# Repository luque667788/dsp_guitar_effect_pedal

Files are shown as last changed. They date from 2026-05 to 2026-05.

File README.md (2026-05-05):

# Noise Maker V1
### Digital Guitar Effect Pedal Prototype with Audio DSP

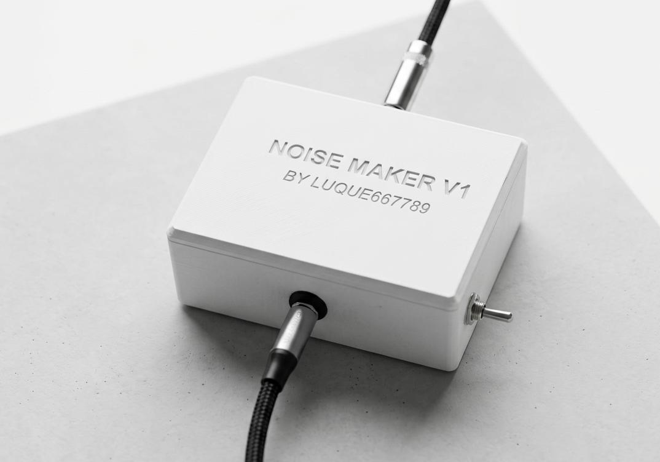
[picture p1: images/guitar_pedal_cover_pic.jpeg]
Noise Maker V1


## Overview

A digital guitar pedal that implements an echo effect on the signal between guitar and amplifier, based on an STM32H7 and custom analog circuits. This is a semester project I built at Hochschule Ravensburg-Weingarten to bring the fundamentals from my theoretical courses (Communication Technology, Computer Technology, Signal Analysis in Time and Frequency Domains, DSP Basics, and Electronic Circuit Design) together into one thing I could plug into and play through (literally :).

Of course this is just a prototype, so there is plenty that can still be improved, especially on the hardware side. More updates will follow as time allows.

The full report and the presentation slides are in [`docs/`](docs/).

## Features

- Real-time audio DSP on a live guitar signal.
- ADC and DAC streaming over DMA, no polling.
- Hardware-timer-driven, interrupt-based sampling pipeline.
- Double-buffering between ADC, memory, and DAC.
- Zero-copy ring buffer for the echo line. Geometric series echo fading.
- Custom analog frontend and backend, designed from scratch around the STM32's built-in converters.
- Filtering before the ADC and after the DAC (sampling-theory-driven, report explains in detail).
- Falstad circuit simulation up front, KiCad schematics for the final design.
- Output noise measured and analyzed in the frequency domain with Audacity (possible sources of noise and future improvements discussed in the report).
- Firmware in C, end-to-end working MVP from analog input to analog output.
- 3D-printed enclosure, 9 V battery powered.

## How it works

The guitar signal is conditioned by an analog frontend, sampled on the STM32H743, processed in real time, and returned through an analog backend to a level the amplifier accepts. A hardware timer drives the sampling, DMA streams the samples in and out with double-buffering, and the delay itself is a ring buffer in memory where only the indexes move. The full design (clock tree, filtering, DSP loop, noise analysis) is explained in detail in the [report](docs/report.pdf). For a high-level overview, see the [presentation slides](docs/presentation.pdf).

## Toolchain

Built with the STM32 toolchain. Peripherals configured in STM32CubeMX, firmware compiled with `arm-none-eabi-gcc` through CMake, flashed over ST-Link.

## What is in this repo

You will find the firmware source code, the KiCad circuit schematics, and the scientific report and presentation slides.

```
.
├── docs/                    slides and scientific report
├── guitar_pedal_software/   STM32H743 firmware
├── kicad/guitarpedalv2/     KiCad schematic and PCB project
└── images/                  schematics, photos, scope captures
```

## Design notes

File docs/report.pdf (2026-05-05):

## Author: Luiz Henrique Mendonça Nr. 17442671

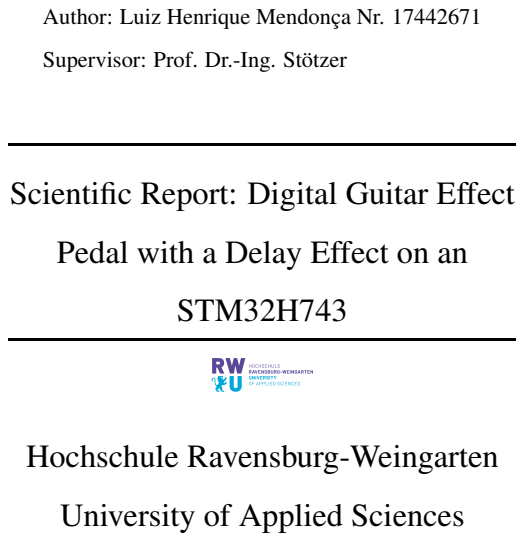
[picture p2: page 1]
STM32H743

Supervisor: Prof. Dr.-Ing. Stötzer

Scientific Report: Digital Guitar Effect

Pedal with a Delay Effect on an

Hochschule Ravensburg-Weingarten

University of Applied Sciences

## Contents

1 Abstract | 2
2 Introduction | 3
3 Materials and Methods | 6
4 Results | 10
5 Discussion | 24
6 Glossary | 27
7 Bibliography | 28

## 1 Abstract

This report describes the design and build of a digital guitar effect pedal that adds

an echo (delay) to the signal of an electric guitar. The pedal sits in the signal

chain between the guitar and the amplifier, and is built around an STM32H743

microcontroller with a minimal analog frontend and backend based on a single

MCP6002 dual op-amp running on a 3.3 V single supply. The frontend conditions

the weak guitar signal so that it can be sampled by the on-chip ADC. The firmware

stores each sample in a circular buffer and plays it back 300 ms later mixed with the

live signal. The backend brings the processed output back to a level and impedance

that a guitar amplifier accepts. The full chain was designed, simulated, prototyped

on a breadboard, soldered onto a protoboard, and finally mounted in a 3D-printed

enclosure. The prototype produced a clearly audible echo on real guitar input,

fulfilling the proposed goals.

2

## 2 Introduction

A delay pedal stores what the guitar plays and repeats it a short time later. The

listener hears the original note and then a quieter copy of it; if part of the copy is

fed back into the delay line, the echoes repeat and gradually fade. The effect has

been used in guitar music since the tape-echo devices of the 1950s, and today it

can be reproduced with a microcontroller and a handful of passive components. It

is a good showcase for a digital effect pedal precisely because long, clean delays

are difficult to achieve in purely analog hardware.

Compared to dedicated audio codecs or application-specific DSP chips, this

minimal-BOM approach leverages the high clock speed and built-in converters

of the STM32H7, alongside a standard single-supply op-amp. This design trades

audio fidelity for hardware simplicity, providing a practical context to explore

mixed-signal embedded engineering constraints.

The central technical problem is moving the analog signal in and out of the

digital domain without introducing noise. A guitar pickup produces a continuous

voltage that swings symmetrically around ground, while a microcontroller works

with discrete numbers sampled at a fixed rate. On top of that, the Nyquist theorem

requires that no frequency component above half the sampling rate reaches the

converter; otherwise that energy folds back into the audible band as aliasing and

produces tones that were never in the original signal. To prevent this, a low-pass

filter is placed before the ADC to remove out-of-band content before sampling,

and an identical filter is placed after the DAC to smooth the stepped output back

into a continuous signal. At a sampling rate of 48 kHz the Nyquist limit limit is

24 kHz, which covers the full audible range. In practice the energy of music sits

well below this limit. Figure 1 shows the frequency distribution of a typical music

signal: most of the energy is below 5 kHz and the audible range tapers off well

before 20 kHz. The anti-alias and reconstruction filters in this project were sized

3

with this in mind.

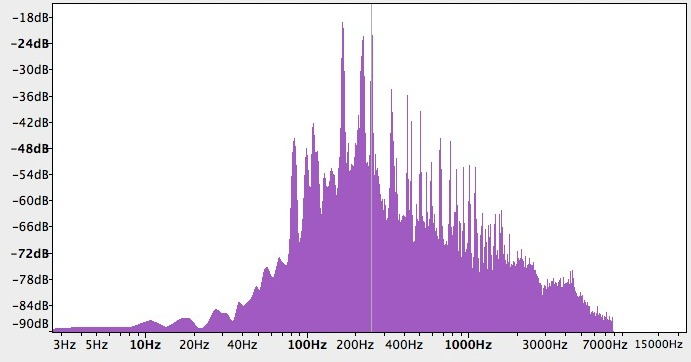
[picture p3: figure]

Figure 1: Frequency distribution of a typical music signal. Most energy is below

5 kHz and the audible range tapers off well before 20 kHz.

The analog signal path uses an op-amp as a unity-gain buffer at the input and

at the output, to give the filter stages a high input impedance toward the guitar

pickup and a low output impedance toward the next stage, so the cutoff of each RC

filter is not pulled by the connected load. A high-pass filter at the output removes

the DC bias that the single-supply circuit adds to the signal, before it reaches

the downstream amplifier. At the ADC input, a pair of BAT54S Schottky diodes

clamps the pin to the supply rails to protect the converter from over-voltage.

On the digital side, a hardware timer drives the sample rate by firing an update

event at 48 kHz, which starts an ADC conversion and latches a DAC output in

hardware without involving the processor. DMA moves data between the converter

peripherals and memory buffers, so the CPU is free to run the delay algorithm

while transfers proceed in the background. Double buffering divides the DMA

buffer into two halves: the hardware fills one half while the processor works on the

other, keeping the audio stream continuous with no gap between conversions.

The goal of this project was to build a working delay pedal at 48 kHz with up to

300 ms of delay, using a single MCP6002 [2] dual op-amp for both analog stages

4

on a 3.3 V supply, and an STM32H743 microcontroller [1] for the digital signal

processing. The project question follows from the goal: Can a working digital

delay effect for an electric guitar be built around an STM32H743 and a single

MCP6002 dual op-amp on a 3.3 V single supply, producing an audible echo on

real guitar input?

5

## 3 Materials and Methods

### 3.1 Materials Used

The microcontroller used was an STM32H743VIT6 [1] on a WeAct Mini devel-

opment board (Figure 2). It is an ARM Cortex-M7 running at up to 480 MHz,

with a 16-bit ADC, a 12-bit DAC, and a DMA controller that moves data between

peripherals and memory without CPU involvement. The analog stages were built

around one MCP6002 dual op-amp and a small set of resistors and capacitors. Two

6.35 mm TS jack jacks carry the input and output signals. All the components and

their values are documented in the circuit diagrams. A Bill of Material (BoM) can

also be provided as an attachment.

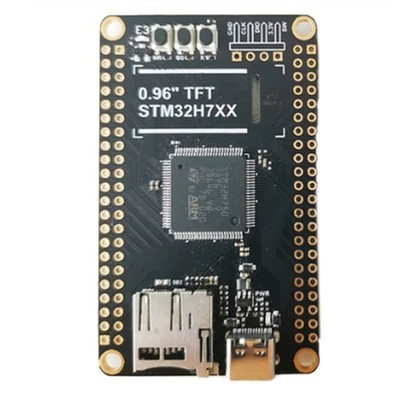
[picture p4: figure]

Figure 2: WeAct Mini STM32H743 development board.

The following tools were used during the project:

- STM32CubeMX, to generate the peripheral initialization code.
- arm-none-eabi-gcc version 12 as cross-compiler, called from CMake.
- KiCad 8, for the schematic capture.

6

- Falstad Circuit Simulator, to check the full analog signal path in the browser

before building it.

- A guitar, a guitar amplifier, and an oscilloscope, for listening tests and

waveform verification.

- Audacity 3, for recording and analysing the pedal output during the verifica-

tion measurements.

### 3.2 Methods

A top-down approach was taken for developing the system architecture. The

sampling rate was fixed first at 48 kHz, which set the Nyquist limit and from there

the cutoff of the anti-alias filter. 48 kHz was chosen over the 44.1 kHz CD rate

because it is the standard rate of professional digital audio equipment and divides

evenly into the 240 MHz timer clock, which avoids drift between the timer period

and the actual sample rate. The component values were then calculated based on

that and the input range the ADC needs based on the STM32 datasheet (so we

know which input and output are expected from the ADC and DAC). Each analog

stage was built on a breadboard and tested on its own with a signal generator before

being connected to the microcontroller, so that problems could be isolated to one

part of the chain at a time.

The firmware was developed in parallel with the hardware. STM32CubeMX

was used to generate the initialization code for the ADC, DAC, timer, and DMA

peripherals; the DSP loop was then developed in a separate module (dsp.h) and

integrated into the DMA callbacks. The code was compiled with CMake and

flashed over ST-Link. The waveforms were verified on the oscilloscope using a

simulated signal from a frequency generator, which made it possible to test the

firmware on its own without depending on the analog stages. The circuit was then

7

moved from the breadboard to a hand-soldered protoboard and assembled in a

3D-printed enclosure (Figure 3).

The verification measurements (results documented in Section 4.6) used the

setup: A 300 Hz sine wave generated on the laptop was sent from the laptop

headphone output into the pedal input jack J1, processed by the pedal, fed into

the guitar amplifier, and recorded back into Audacity through the amplifier’s

USB output at 48 kHz, 16-bit. A second recording was taken with the laptop

disconnected from J1, capturing the noise alone. Both recordings used identical

amplifier and recorder gain settings, so the gain factor cancels in the ratio of the

two and the system SNR can be derived directly from the dBFS difference between

them.

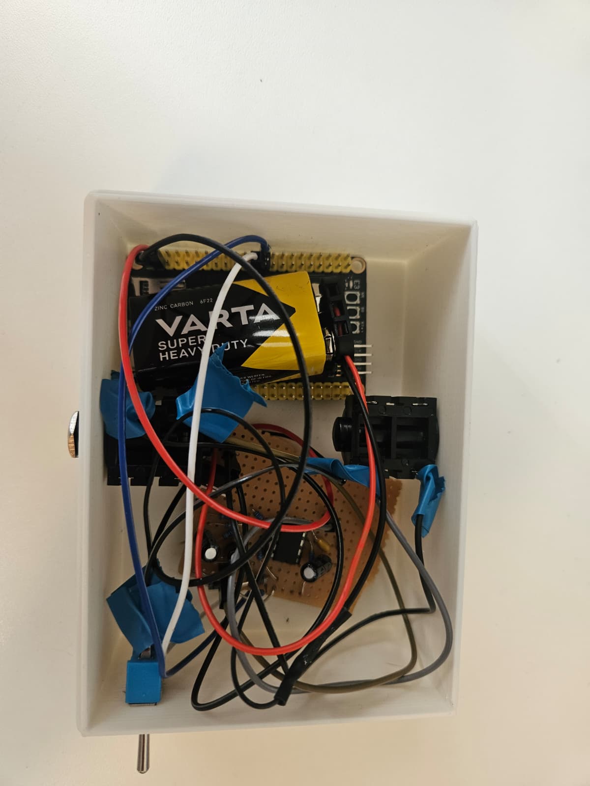
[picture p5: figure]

Figure 3: Final prototype in its 3D-printed enclosure, powered by a 9 V battery.

8

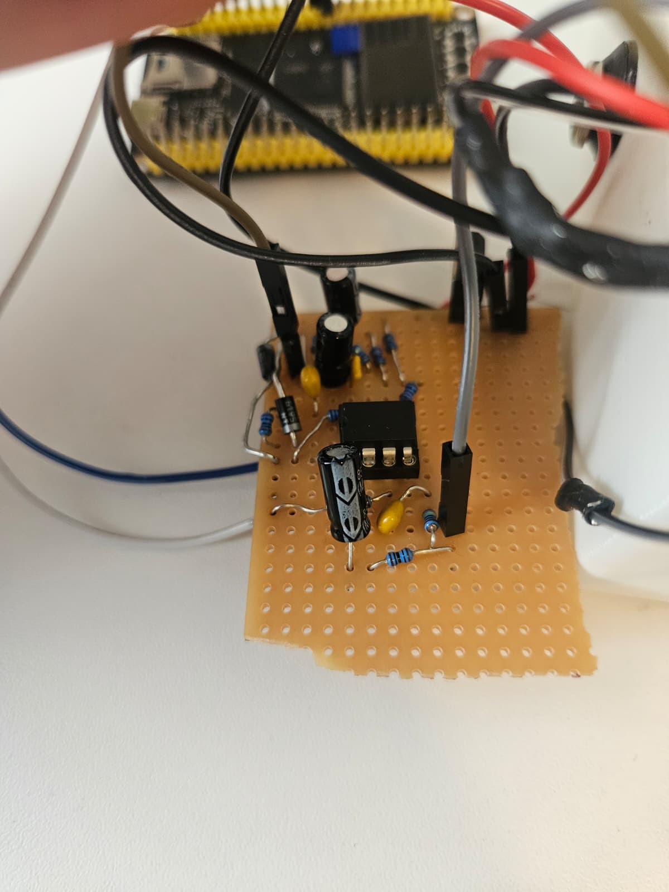
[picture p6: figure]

Figure 4: Hand-soldered protoboard with the analog frontend, backend, and

STM32H743 development board.

9

## 4 Results

The results is the design of a system that was divided in two main parts: the analog

frontend/backend, and the software architecture of the firmware. In the sections

below both designs are described and explained:

### 4.1 Analog Frontend

The frontend conditions the guitar signal before it reaches the ADC. Figure 5 shows

the schematic. Signal flow is left to right; each component is described below.

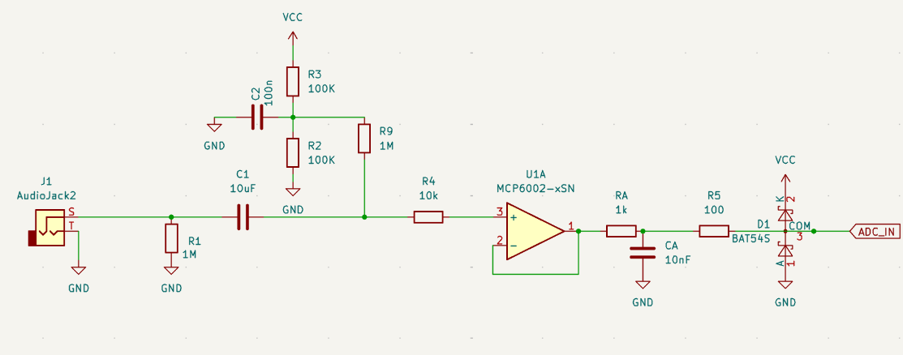
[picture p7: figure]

Figure 5: Analog frontend: guitar input to ADC pin.

J1 — 6.35 mm TS jack. Guitar input.

R1 — 1 MΩ to GND. Sets input impedance to 1 MΩ, which is what a guitar

pickup expects. Also bleeds charge off C1 when the cable is unplugged, preventing

a pop on reconnection.

C1 — 10 µF. AC-coupling capacitor. Blocks any DC from the source; passes

audio. The high-pass corner with R1 is

fc =

1
2π · 1 MΩ · 10 µF
≈ 0.016 Hz, | (4.1)

well below the lowest guitar note, so no signal is lost.

10

R2, R3 — 100 kΩ each (bias divider). Divide the 3.3 V supply to produce a

DC midpoint:

Vbias =

3.3
2
= 1.65 V. | (4.2)

The guitar signal swings around 0 V; the ADC input range is 0 V to 3.3 V. Lifting

the signal onto the 1.65 V midpoint centers its swing inside the full ADC range.

C2 — 100 nF. Decouples the bias node to GND. Keeps the 1.65 V reference

stable against VCC variations.

R9 — 1 MΩ. Connects the bias node to the signal path. The Thévenin

impedance of R2/R3 is 50 kΩ. Without R9, that 50 kΩ would load the signal

and interact with the source impedance, attenuating high frequencies (tone suck).

R9 raises the impedance seen by the signal to 50 kΩ + 1 MΩ ≈ 1.05 MΩ, which is

negligible next to R1.

R4 — 10 kΩ. Series resistor at the op-amp non-inverting input. Limits input

current in fault conditions and damps any resonance with op-amp input capacitance.

U1A — MCP6002, unity-gain buffer. Output tied directly to inverting input.

Input impedance ≈ 10¹² Ω; output impedance < 1 Ω. Isolates the high-impedance

bias divider from the low-impedance filter that follows.

RA, CA — 1 kΩ and 10 nF C0G. Anti-aliasing low-pass filter:

fc =

1
2π · 1 kΩ · 10 nF
≈ 15.9 kHz. | (4.3)

The cutoff sits above the band where musical content lives (Figure 1) and below the

24 kHz Nyquist limit, so it removes out-of-band energy before sampling without

cutting useful signal.

R5 — 100 Ω. Protection resistor at the ADC pin. Limits fault current through

the STM32 internal ESD diodes if a transient drives the pin outside the supply

rails.

D1 — BAT54S dual Schottky. Clamp diodes at the ADC pin. One diode from

11 pin to VCC, one from pin to GND. Forward voltage ≈ 0.3 V: the pin is clamped to

the range [−0.3 V, 3.6 V] before any transient reaches the converter input.

### 4.2 Analog Backend

The backend converts the DAC output back to a line-level audio signal. Figure 6

shows the schematic. Signal flow is left to right; each component is described

below.

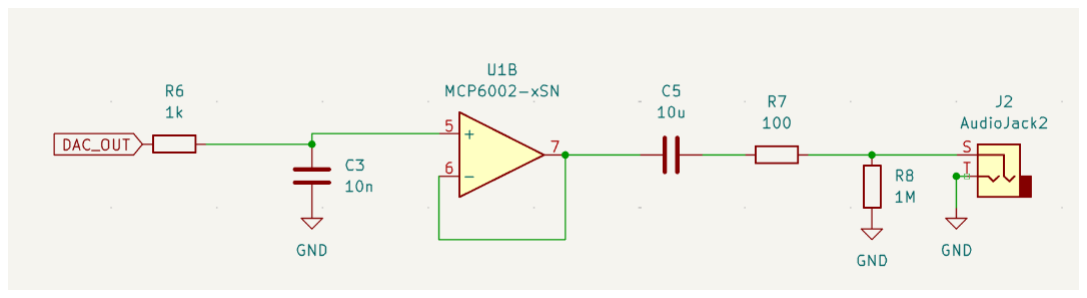
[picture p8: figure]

Figure 6: Analog backend: DAC output to amplifier jack.

R6 — 1 kΩ. Series resistor at the DAC output. Together with C3 it forms the

reconstruction low-pass filter (see C3 below).

C3 — 10 nF C0G. Together with R6, forms the reconstruction low-pass filter:

fc =

1
2π · 1 kΩ · 10 nF
≈ 15.9 kHz. | (4.4)

The DAC holds each sample constant until the next clock tick, producing a staircase

waveform. The filter smooths those steps before the signal reaches the op-amp.

The cutoff matches the anti-aliasing filter on the frontend, so both edges of the

digital window are treated symmetrically.

U1B — MCP6002, unity-gain buffer. Second channel of the same dual

op-amp used in the frontend. Output tied directly to inverting input. Presents a

high-impedance load to C3 so the filter corner stays at 15.9 kHz, and drives the

output network from a low-impedance source.

12

C5 — 10 µF. AC-coupling capacitor at the op-amp output. The DAC runs with

a 1.65 V DC midpoint bias; C5 blocks this offset so the output delivered to the

amplifier is centered on 0 V.

R7 — 100 Ω. Series resistor at the output node. Limits fault current through

the op-amp output stage if the jack is shorted or connected to a low-impedance

load, and damps any cable capacitance resonance.

R8 — 1 MΩ to GND. Bleeder resistor at the output node. Provides a DC return

path so C5 does not float the output when no amplifier is connected. Also forms a

high-pass corner with C5:

fc =

1
2π · 1 MΩ · 10 µF
≈ 0.016 Hz, | (4.5)

negligible relative to the audio band.

J2 — 6.35 mm TS jack. Output to guitar amplifier.

13

The full analog path was also entered into the Falstad simulator to check the

frontend and the backend together before building the circuit. Figure 7 shows the

simulated chain.

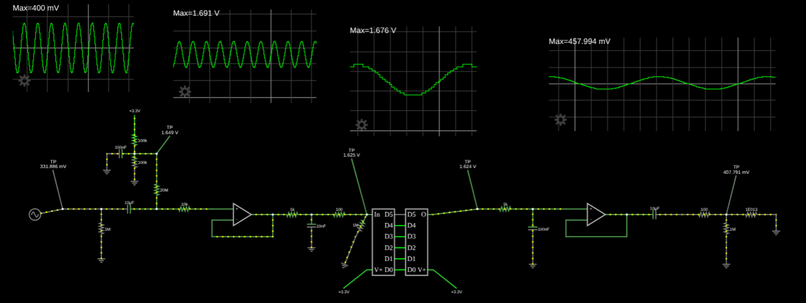
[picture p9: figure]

Figure 7: Falstad simulation of the full analog path: frontend on the left, backend

on the right. Simulated ADC-DAC in the middle

### 4.3 Software Architecture

The firmware is built around the idea that the CPU should not be involved in the

timing of the signal chain at all. The sampling rate is generated in hardware, the

data is moved by DMA, and the CPU only wakes up when a new block of samples

is ready to process. Figure 8 shows the overall flow.

14

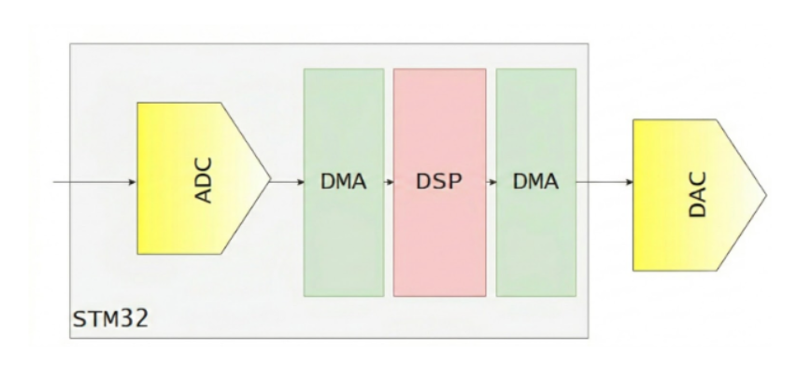
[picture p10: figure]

Figure 8: Signal flow from guitar input to amplifier output.

The internal HSI 64 MHz RC oscillator is configured through the PLL to

produce a 480 MHz system clock. After the bus prescalers, TIM6 receives a

240 MHz input clock. With a counter period of 5000 ticks, it fires an update event

at

fs =

240 MHz
5000
| | = 48 kHz. | (4.6)

Listing 1 shows the relevant lines from Src/tim.c (file auto-generated by

STM32CubeMX HAL boilerplate generator). The period register is written as

5000 - 1 because the counter counts from zero to Period inclusive, so 5000

ticks elapse before each reset. The MasterOutputTrigger setting routes that

reset event onto the internal trigger bus (TRGO) so ADC1 and DAC1 can act on it

without any software involvement.

1 | htim6.Instance | = TIM6;
2 | htim6.Init.Prescaler | = 0;
3 | htim6.Init.CounterMode | = TIM_COUNTERMODE_UP;
4 | htim6.Init.Period | = 5000 - 1; | // 240 MHz / 5000 =
| 48 kHz
5 | htim6.Init.AutoReloadPreload = TIM_AUTORELOAD_PRELOAD_DISABLE;

15

6 HAL_TIM_Base_Init(&htim6);

7

8 | sMasterConfig.MasterOutputTrigger = TIM_TRGO_UPDATE;
9 | HAL_TIMEx_MasterConfigSynchronization(&htim6, &sMasterConfig);

Listing 1: TIM6 period and master trigger configuration (Src/tim.c).

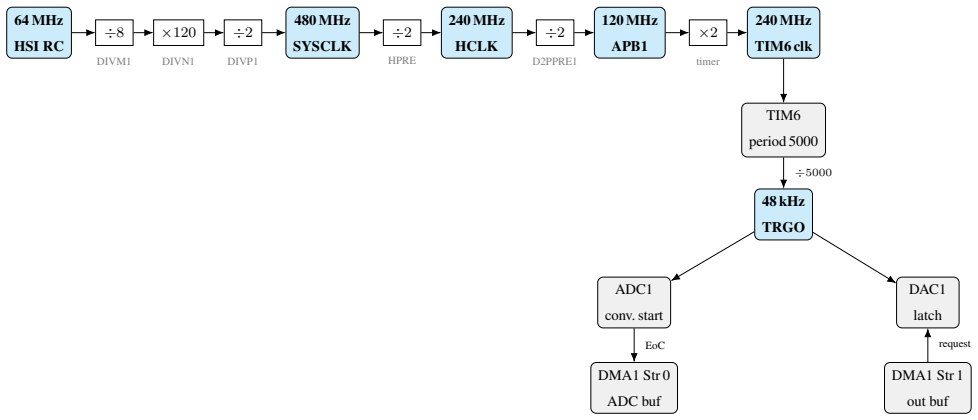
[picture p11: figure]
64 MHz; HSI RC; 480 MHz; SYSCLK; DIVM1; DIVN1; DIVP1; 240 MHz; HCLK; HPRE; 120 MHz; APB1; D2PPRE1; TIM6 clk; timer; TIM6; period 5000; 48 kHz; TRGO; ADC1; conv. start; DAC1; latch; DMA1 Str 0; ADC buf; DMA1 Str 1; out buf; EoC; request

Figure 9: Clock path from HSI to the TIM6 TRGO pulse at 48 kHz, and the

resulting trigger chain to ADC1 and DAC1. Value boxes (blue) show the frequency

at each node; prescaler boxes (white) show the division or multiplication applied.

The ×2 timer doubler is automatic on the STM32H7 whenever the APB1 prescaler

is greater than 1, restoring the timer input to 240 MHz. TIM6 counts 5000 ticks of

its 240 MHz input and then resets, producing the 48 kHz update event. That event

is broadcast on the internal trigger bus (TRGO) and starts one ADC conversion

and latches one DAC output simultaneously. The DMA streams are then driven by

the peripherals themselves (ADC end-of-conversion for DMA1 Stream 0; DAC

sample-needed request for DMA1 Stream 1), not by TIM6 directly.

This event is routed to the internal trigger bus and used as the master tick for

both the ADC and the DAC. Both peripherals are configured to act on that trigger:

the ADC starts a conversion, the DAC latches the next output sample. Neither the

16

CPU nor any software is involved in keeping this timing; the hardware runs the

loop on its own [5].

The DMA controller moves the data. The ADC fills a 256-sample circular

buffer in memory, and the DAC drains a matching 256-sample output buffer. The

most relevant code logic lies in how the CPU interacts with those buffers. The DMA

raises an interrupt after the first 128 samples have been written (half-complete) and

another after all 256 (complete). On the first interrupt, the CPU processes samples

0–127 of the input and writes results to samples 0–127 of the output. While it does

that, the DMA is already filling samples 128–255 on the input side. On the second

interrupt the roles swap: the CPU handles the second half while the DMA wraps

back to the beginning. The CPU and the DMA always work on different halves, so

neither ever has to wait for the other [4]. The DSP routine has at most

128
48 000 Hz
≈ 2.67 ms | (4.7)

to finish processing one half-buffer before the DMA overwrites it.

### 4.4 Delay Algorithm

The delay effect uses a circular buffer of 14 400 int16_t values. A write pointer

advances one position per sample, and a read pointer follows 14 400 positions

behind it; both wrap back to zero at the end of the buffer. Because the buffer is

14400
48 000 Hz
= 300 ms | (4.8)

long, the read pointer always returns a sample recorded 300 ms ago. No

memory is ever copied or shifted; both pointers just step forward by one and wrap,

so the cost per sample is independent of the delay length.

17

The DSP routine processes 128 samples per call, matching the half-buffer size.

Listing 2 shows the complete loop.

1 | #define DELAY_LEN 14400
2 | static int16_t | delay_buf[DELAY_LEN];
3 | static uint32_t write_idx = 0;
4 | static uint32_t read_idx | = 1;

5

6 | for (uint32_t i = 0; i < HALF_BUFFER; i++) {
7 | int32_t dry | = ((int32_t)input[i] - ADC_MID) >> 4;
8 | int32_t delayed = delay_buf[read_idx];

9

10 | int32_t fb = dry + (delayed >> 1); | // 50% feedback
11 | if (fb > | 2047) fb = | 2047;
12 | if (fb < -2048) fb = -2048;
13 | delay_buf[write_idx] = (int16_t)fb;

14

15 | int32_t out = DAC_MID + dry + ((delayed * 6) / 10); // 60%

wet

16 | if (out > 4095) out = 4095;
17 | if (out < 0) | out = 0;
18 | output[i] = (uint16_t)out;

19

20 | write_idx = (write_idx + 1) % DELAY_LEN;
21 | read_idx | = (read_idx | + 1) % DELAY_LEN;
22 | }

Listing 2: Delay DSP loop.

The first line inside the loop re-centers the ADC sample and scales it to fit the

DAC range. The ADC produces unsigned 16-bit values (0 to 65535) centered at

32768 (ADC_MID). Subtracting the midpoint gives a signed value around zero;

shifting right by four bits divides by sixteen, mapping the result to the range −2048

to +2047. This is the signed 12-bit range that the DAC works in. The shift costs

18 no multiplication operation and maintains the precision.

The next line reads delayed, which is whatever value was written into the

buffer 14 400 samples (300 ms) ago. The feedback calculation that follows is the

mechanism behind repeating echoes: half of that delayed value (delayed » 1,

integer division by two) is added to the dry sample, and the result is written back

into the buffer at write_idx. When this feedback value is read back 300 ms

later, it will itself contain a mix of dry and previous echo, producing a new echo

from an echo. Because the delayed component is halved on every pass, the echoes

decay as 0.5, 0.25, 0.125, . . . a geometric series with ratio 0.5 [3]. Reaching the

conventional −60 dB perceptual floor (amplitude 10⁻³ of the original) takes

n =

log0.5

(10⁻³
)
= 10 repeats, | (4.9)

which at 300 ms per repeat is about 3 s of audible tail before the echo dies out. The

clamp to ±2047 prevents integer overflow from accumulating; without it, a loud

note could drive the feedback into saturation and the echoes would never fade.

The output line assembles the final sample. The dry signal is kept at full

amplitude and the delayed signal is mixed in at 60 % ((delayed * 6) / 10),

so the echo is clearly audible but quieter than the original note. DAC_MID (2048)

is then added back to restore the unsigned offset that the 12-bit DAC requires.

A second clamp keeps the result inside the 0–4095 range. Both index pointers

advance and wrap at the end of each iteration. It should be noted that repeated

integer division and truncation in this feedback loop introduces fresh quantization

noise on each pass.

The double-buffering scheme adds one full buffer of pipeline latency:

tlat =

256
48 000 Hz
≈ 5.33 ms. | (4.10)

This is the unavoidable cost of processing samples in blocks rather than one at

a time. Whether this delay is perceptible in playing is checked in Section 4.6.

19

### 4.5 Development Issues and Fixes

There were two main issues during development. First, the DMA1 controller

cannot read the DTCM memory that the compiler uses by default. The audio

buffers had to be set explicitly in the D2 SRAM region using a linker attribute.

Before this fix, the system produced no sound and showed no error flags.

Second, a scaling bug showed how the algorithm depends on converter ranges.

An early firmware version missed the right-shift on the first line of the DSP loop

(Listing 2). Because of this, the raw 16-bit ADC sample (0–65535) was written

directly to the 12-bit DAC buffer. Any sample value over 4095 saturated the

DAC immediately, clipping the output to the maximum level for almost the whole

waveform.

Figure 10 shows the three signals captured on the oscilloscope at that point.

The yellow trace is the reference signal from a bench signal generator feeding the

pedal input. The blue trace is the analog frontend output: the same signal shifted

up by 1.65 V so that it sits in the positive range the ADC expects. The purple trace

is the DAC output without the bit-shift correction: it is driven hard to the supply

rail for most of each cycle and bears no resemblance to the input.

20

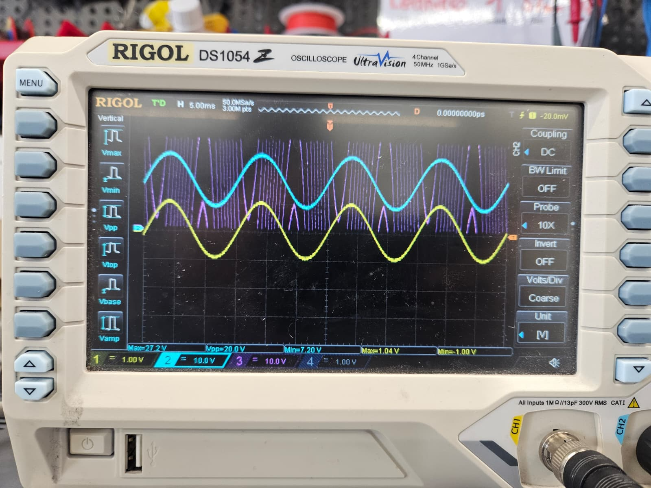
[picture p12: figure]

Figure 10: Oscilloscope capture during development. Yellow: signal generator

input. Blue: analog frontend output (DC-biased to 1.65 V). Purple: DAC output

without the 16-bit-to-12-bit scaling, showing full-scale saturation.

Once the right-shift was added, the output waveform tracked the input correctly.

The bit-shift also sets the resolution of the reconstructed audio. The output

dynamic range depends on the 12-bit DAC, not the 16-bit ADC, because the lower

four bits of each sample are discarded.

In digital audio, every bit of resolution halves the quantization error, which adds

roughly 6 dB to the signal-to-noise ratio. For a full-scale sine wave, the theoretical

maximum signal-to-quantization-noise ratio (SNRq) of an ideal N-bit converter is

defined by the formula 6.02 · N + 1.76. Using N = 12 for the DAC, this gives:

SNRq = 6.02 · 12 + 1.76 ≈ 74 dB. | (4.11)

This 74 dB theoretical limit provides comfortable headroom for a guitar signal [3].

### 4.6 Verification

Two checks were made on the assembled prototype: the pipeline latency against

the threshold reported for live playing, and the noise floor at the output.

21

The pipeline latency from the input jack to the output jack is the 5.33 ms value

derived above. This latency falls well below the 10 ms threshold typically cited as

the onset of perceptible delay for live performance.

Using the recording chain described in Section 3, Audacity’s Contrast tool

returned an RMS level of −19.91 dB for the 300 Hz reference tone and −40.74 dB

for the noise-only recording, giving

SNRsys = −19.91 − (−40.74) = 20.83 dB | (4.12)

at the test signal level. This figure includes the amplifier’s noise contribution, since

the amplifier is part of the recorded chain. The tone signal did not clip in any stage

of the recording. A frequency analysis of the same recording (Figure 11) shows the

300 Hz reference tone as a narrow spike rising above a broadband noise floor, with

no narrow peak at 50 Hz or its harmonics; mains hum is therefore not a significant

contributor. A low static was audible at the output during the test but did not mask

the guitar tone or the echo when playing.

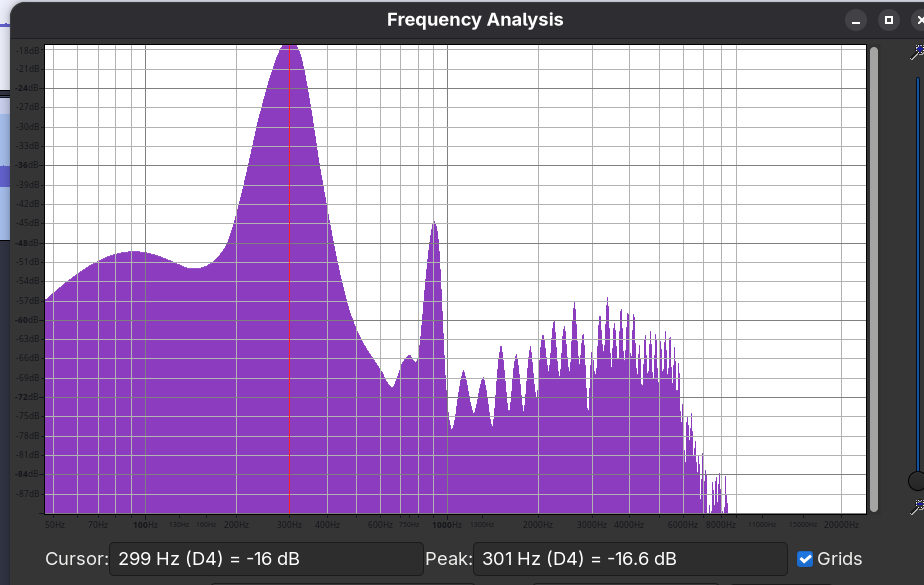
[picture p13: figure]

Figure 11: Frequency spectrum of the 300 Hz reference-tone recording at the

amplifier USB output.

22

In summary, all subsystems: analog frontend, analog backend, firmware, and

DSP algorithm functioned as specified, although audible noise was present.

23

## 5 Discussion

The project question was whether a working delay effect could be built around an

STM32H743 and a single MCP6002 dual op-amp on a 3.3 V single supply, with

an audible echo on real guitar input. The answer is yes. The frontend pushed the

guitar signal into the range the ADC needed, the firmware ran the 300 ms delay

with feedback at 48 kHz without dropouts, and the backend brought the result back

to a level the amplifier accepts. On a real guitar the echo came through clearly.

The problems that showed up during the work were all on the analog and assembly

side, not in the firmware.

### 5.1 Limitations

A low static was audible at the output. It did not cover the guitar tone or the echo,

but the system signal-to-noise ratio reported in Section 4.6 is only 20.83 dB. There

is a large difference between this result and the theoretical quantization-noise floor

of 74 dB expected from a 12-bit DAC. This shows that the main noise comes from

the analog circuit and the board layout. This gap happens for three main reasons:

- Underutilized ADC Headroom: The analog frontend is a unity-gain buffer.

A standard passive guitar pickup generates a peak-to-peak signal of 100 mV

to 300 mV. Because we feed this unamplified signal into the ADC’s full

3.3 V range, it uses less than 10% of the digital headroom. This wastes a lot

of the digital resolution during sampling. It raises the noise floor before the

signal reaches the DSP.

- Shared Power Supply and Grounding: The circuit was built on a hand-

soldered protoboard with no continuous ground plane. The 3.3 V analog

power comes directly from the development board, so it shares the line with

24 the fast ARM microcontroller. Digital current spikes on this shared power

line change the DC bias voltage of the analog stages. This injects switching

noise directly into the audio path.

- Component Selection and Filtering: The MCP6002 works well for 3.3 V

single-supply circuits, but its input noise (≈ 8 nV/

√
Hz) is too high for

good audio. Also, the first-order passive RC anti-aliasing filter has a weak

−6 dB/octave roll-off. At the 24 kHz Nyquist limit, the attenuation is only

about 3.6 dB. This lets high-frequency noise from the shared power supply

alias back into the audible band.

PCB Reliability. The hand-soldered protoboard was physically fragile and

caused bad connections during testing. Moving to a custom printed circuit board

would fix these mechanical problems and also provide the ground planes needed to

reduce the noise.

### 5.2 Future work

A custom two-layer PCB with a continuous ground plane and a separate analog

3.3 V regulator would address both the noise and the contact-reliability limitations

identified above. Replacing the single-pole RC anti-aliasing and reconstruction

filters with a second-order Sallen–Key topology would give a steeper roll-off above

the audible band and reduce out-of-band noise reaching the converters.

The current enclosure is larger than a commercial pedal because the WeAct

Mini development board takes up most of the floor area. Mounting the STM32H743

directly on a custom PCB would shrink the unit to a standard guitar-pedal size.

The prototype has no true-bypass switch, so the signal path is broken when the

pedal is unpowered. A bypass relay or a mechanical true-bypass switch would be

needed for stage use. On the firmware side, the current build runs a single fixed

25 effect; the H743 has enough flash and RAM to hold several DSP modules and

switch between them at runtime, so adding a footswitch-selectable set of effects

(chorus, reverb, distortion) would be a natural extension.

26

## 6 Glossary

ADC Analog-to-Digital Converter. 2, 3, 5

DAC Digital-to-Analog Converter. 3, 5

DMA Direct Memory Access, a peripheral that moves data between memory and

another peripheral without CPU involvement. 4, 5, 12, 14

KiCad Open-source suite for schematic capture and printed circuit board design.

5

MCP6002 Dual rail-to-rail single-supply op-amp used in both the analog frontend

and the analog backend. 2, 4, 5, 20

STM32CubeMX Graphical tool from ST that generates peripheral initialization

code for STM32 microcontrollers. 5, 6

TIM6 One of the basic timers in the STM32H7, used here to trigger both the ADC

and the DAC at 48 kHz. 12, 13

27

## 7 Bibliography

## References

[1] STMicroelectronics, “STM32H743 datasheet,” [Online]. Available: https:

//www.st.com/resource/en/datasheet/stm32h743vi.pdf.

[2] Microchip Technology, “MCP6001/2/4 datasheet,” [Online]. Available: http

s://www.microchip.com/en-us/product/MCP6002.

[3] S. W. Smith, The Scientist and Engineer’s Guide to Digital Signal Process-

ing, https://www.dspguide.com/pdfbook.htm California Techni-

cal Publishing, 1997.

[4] Phil’s Lab, “STM32 Audio Series,” [Online]. Available: https://www.yo

utube.com/@PhilsLab. (https://www.youtube.com/@PhilsLab)

[5] STMicroelectronics, “RM0433: STM32H742, STM32H743/753 and

STM32H750 Value line MCUs reference manual,” [Online]. Available:

https://www.st.com/resource/en/reference_manual/rm

0433-stm32h742-stm32h743753-and-stm32h750-value-l

ine-advanced-armbased-32bit-mcus-stmicroelectronic

s.pdf. (https://www.st.com/resource/en/reference_manual/rm0433-stm32h742-stm32h743753-and-stm32h750-value-line-advanced-armbased-32bit-mcus-stmicroelectronics.pdf)

28

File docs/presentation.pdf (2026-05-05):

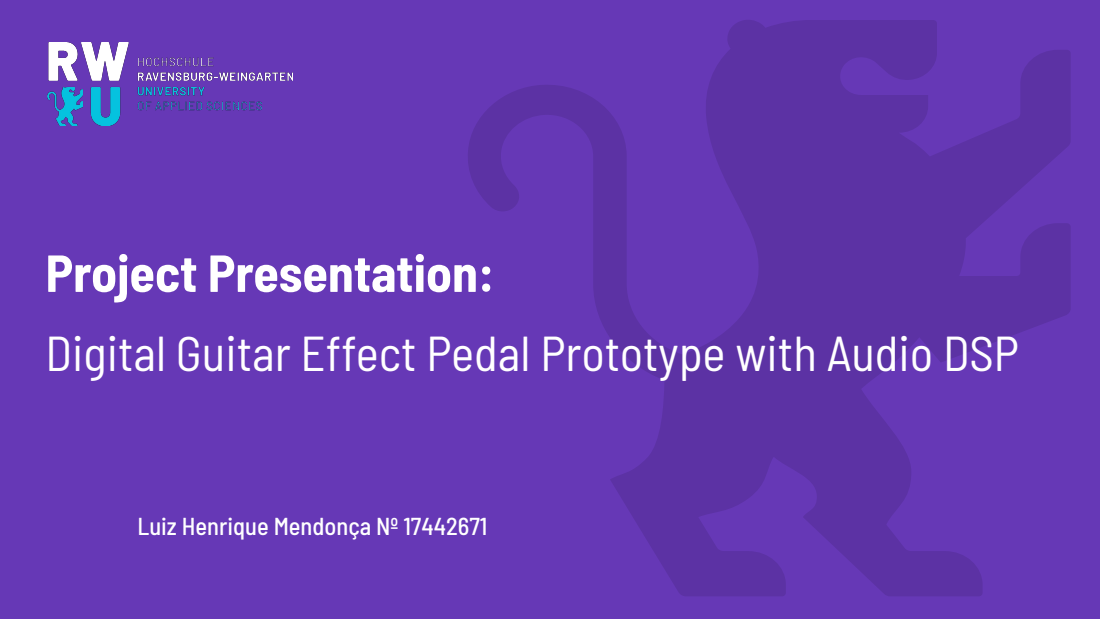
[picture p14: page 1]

Project Presentation:
Digital Guitar Effect Pedal Prototype with Audio DSP

Luiz Henrique Mendonça Nº 17442671

## Introduction

### What is it? What does it do? Why build it?

- Concept: Guitar effect pedals take sound from
guitar input apply effects/distortions to it and forward to the guitar amp
- What was done different: Traditionally guitar pedals are done with analog components. Digital Effect pedals allow more complex effect and to be modified easily without changing hardware
- How was it done? By using DSP concepts we can digitally process audio with a microcontroller. The way the audio signal is transferred to the digital word is through the use of ADC and DAC components. It is practical application of many theoretical concepts learned at school.
- Outcome: Portable functional effect box that
implements “Echo” effects to audio.

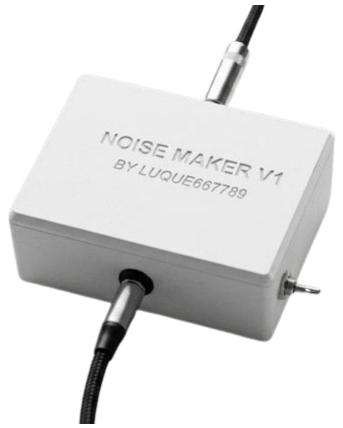
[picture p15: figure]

25.04.2026 | Luiz Mendonça, Scientific Project, SS2026 | 2

## System Components Overview

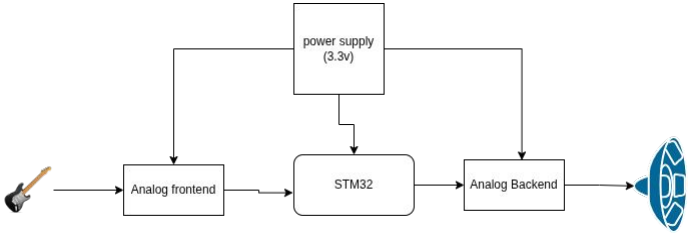
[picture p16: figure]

Luiz Mendonça, Scientific Project, SS2026 | 3
- Analog Frontend: Makes guitar signal fit ADC input range. Sets impedance, adds 1.65 V DC bias, buffers with op-amp, filters at 15.9 kHz.
- STM32H743 (Cortex-M7, 480 MHz): Samples at 48 kHz with hardware timer + DMA. Runs delay algorithm while data transfers happen in background.
- Analog Backend: Smooths DAC output with 15.9 kHz filter, removes 1.65 V bias, sends signal to amplifier.

25.04.2026

## Digital Hardware-to-Software Architecture and Concepts

### How does the digital world interacts with the analog?

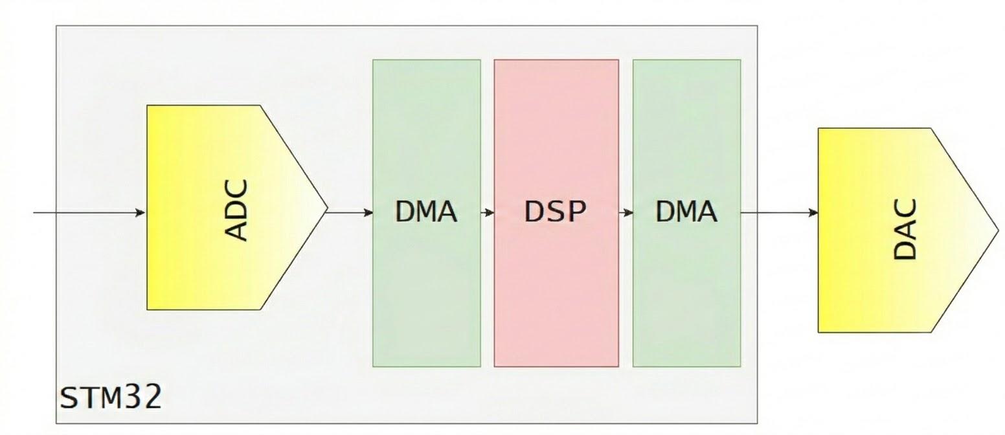
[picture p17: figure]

- 48 kHz Sample Rate: TIM6 at 240 MHz / 5000 = 48 kHz. Triggers ADC and DAC each tick. CPU not involved.
- ADC (16-bit): Reads guitar voltage (0-3.3 V, biased at 1.65 V). Only upper 12 bits used to match DAC.
- DMA: Moves data between ADC/DAC and memory without CPU. CPU wakes only on half-buffer and full-buffer interrupts.
- DAC (12-bit): Converts processed samples to analog. 16-to-12 bit shift drops lower 4 bits, theoretical SNR floor = 74 dB.

## DMA, Hardware Timers & Interrupts

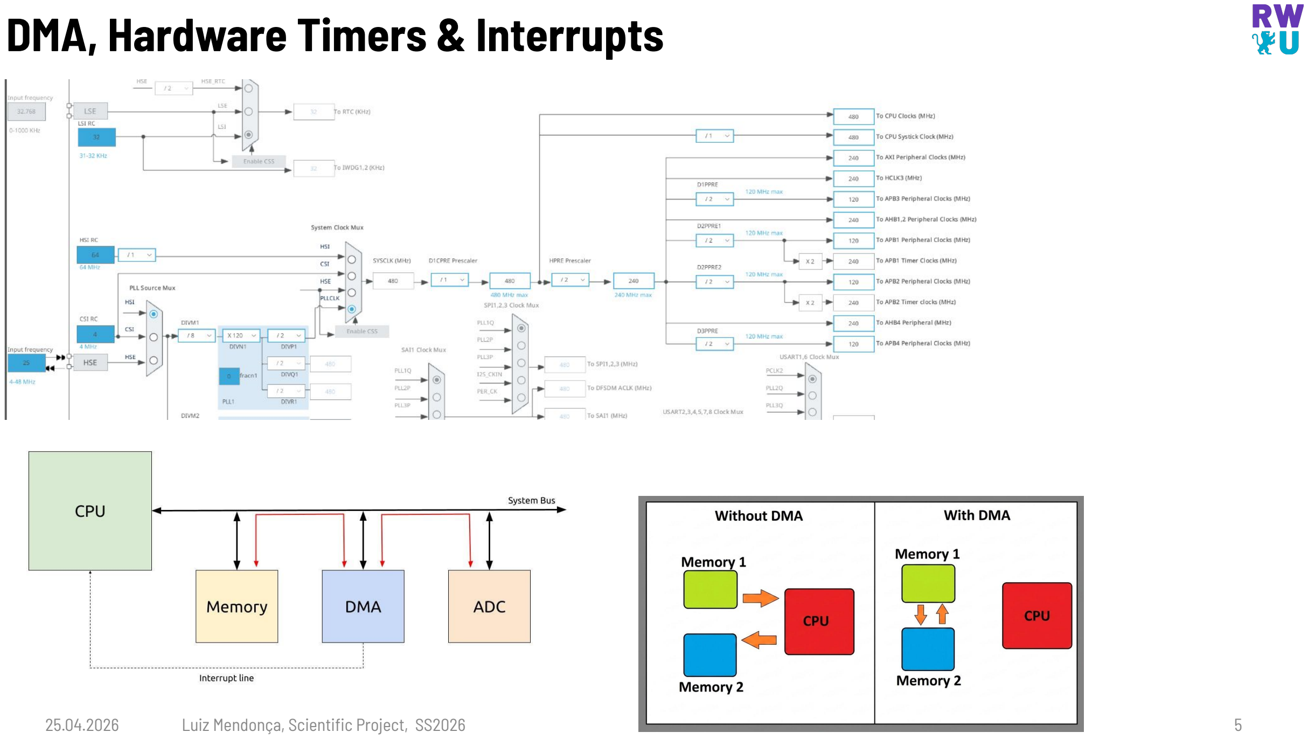
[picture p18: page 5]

25.04.2026 | Luiz Mendonça, Scientific Project, SS2026 | 5

## Analog Circuits Schematics

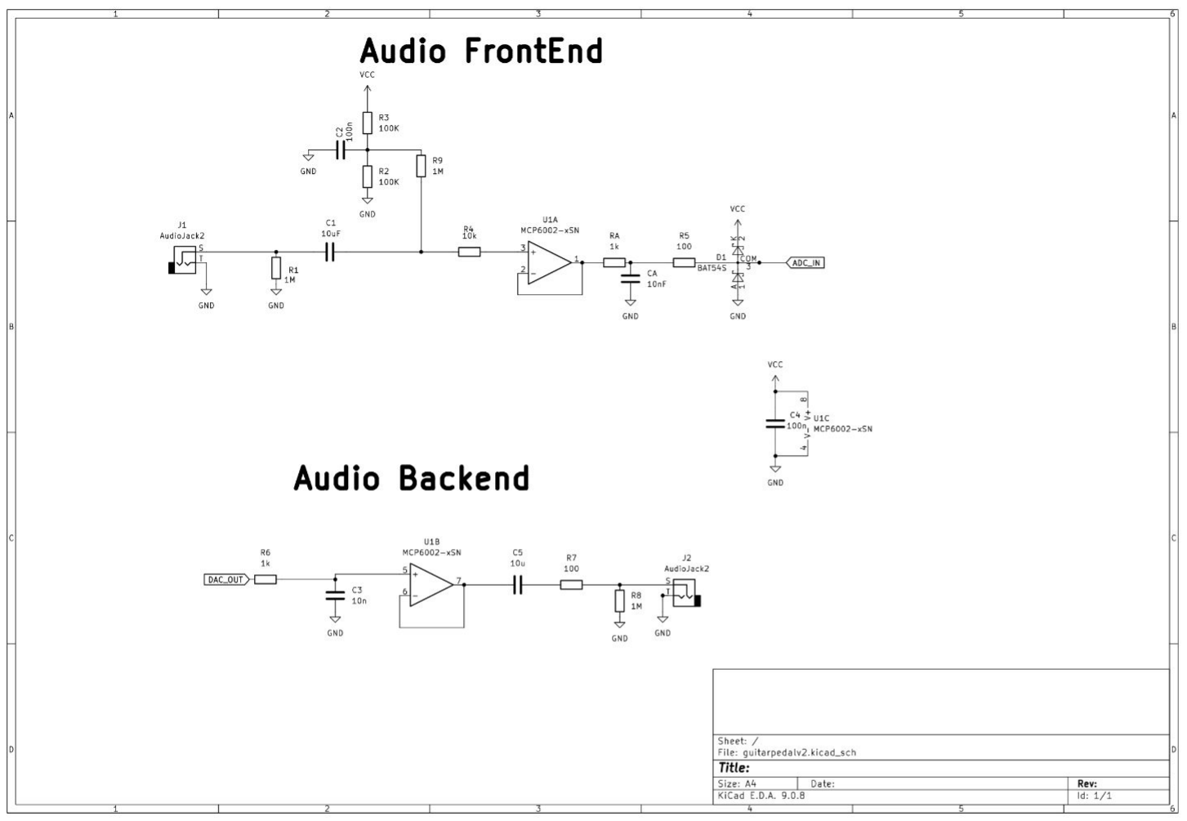
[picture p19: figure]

What the circuit does?:

- Match Impedance
- Center Voltage at 1.65V
- Buffer / Increase Signal Strength
- Filter Frequencies
- Protect the STM32 from Over Voltage or Current

Circuit Simulation (https://www.falstad.com/circuit/circuitjs.html)

## DSP Echo Effect Algorithm

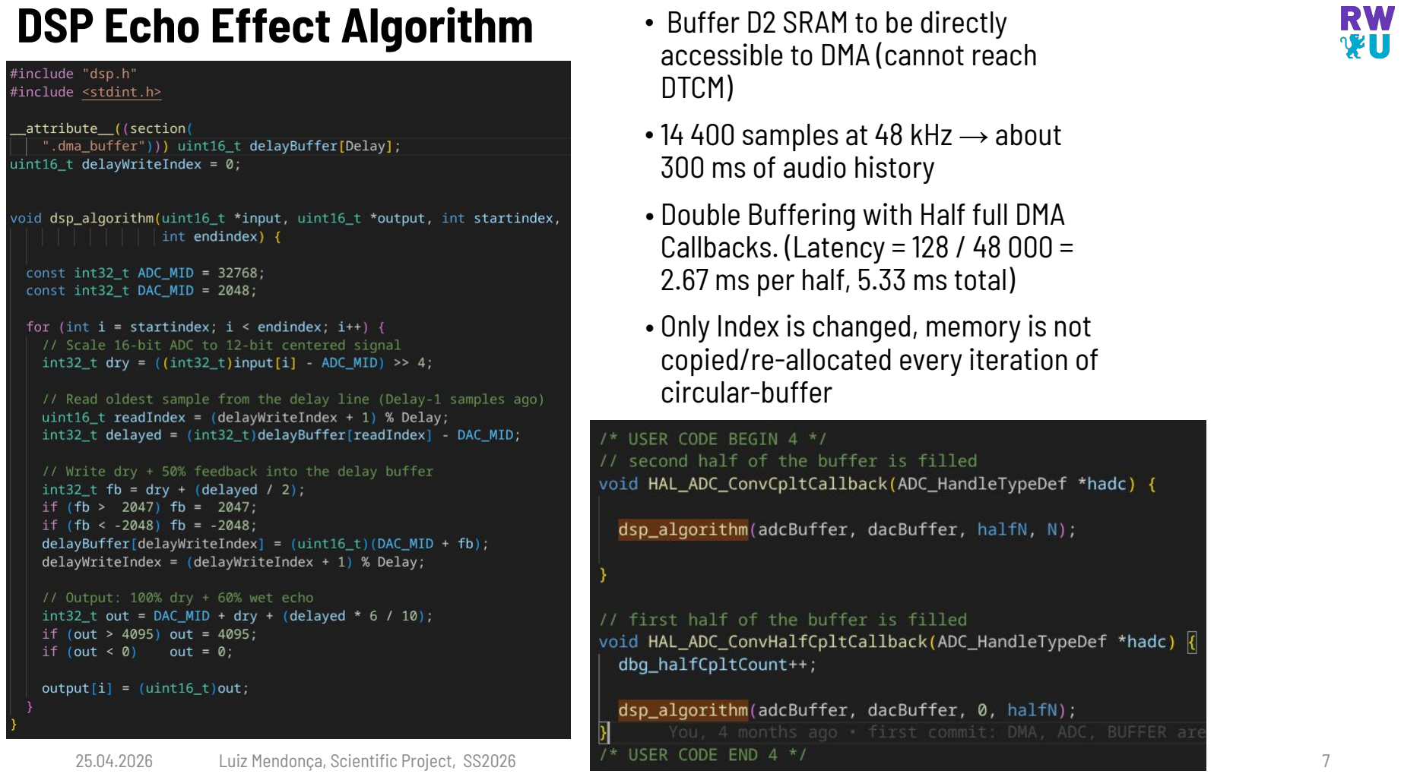
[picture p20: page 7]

- Buffer D2 SRAM to be directly accessible to DMA (cannot reach DTCM)
- 14 400 samples at 48 kHz → about 300 ms of audio history
- Double Buffering with Half full DMA Callbacks. (Latency = 128 / 48 000 = 2.67 ms per half, 5.33 ms total)
- Only Index is changed, memory is not copied/re-allocated every iteration of circular-buffer

## Soldering and System Implementation of Electronics

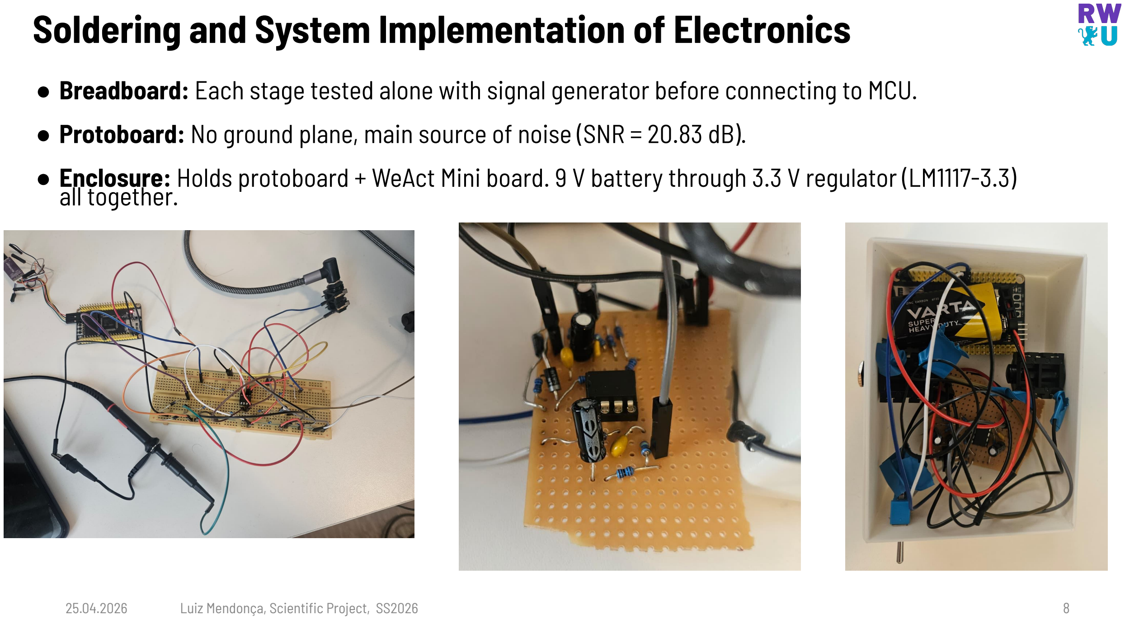
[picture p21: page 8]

- Breadboard: Each stage tested alone with signal generator before connecting to MCU.
- Protoboard: No ground plane, main source of noise (SNR = 20.83 dB).
- Enclosure: Holds protoboard + WeAct Mini board. 9 V battery through 3.3 V regulator (LM1117-3.3) all together.

## Development Tools Environment

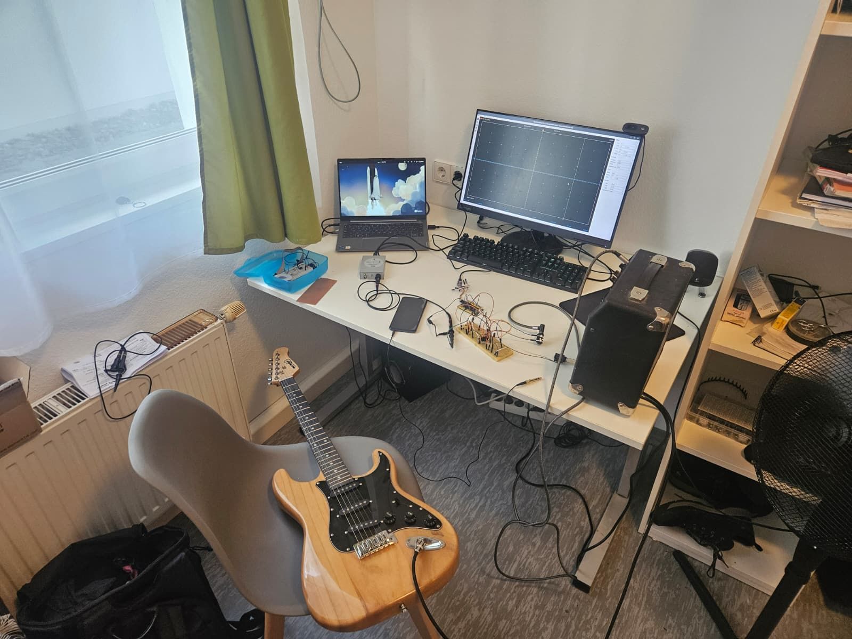
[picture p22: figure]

- STM32CubeMX: Configures ADC, DAC, TIM6, DMA peripherals. Generates HAL init code.
- arm-none-eabi-gcc v12 + CMake: Cross-compiler for Cortex-M7. CMake generates Makefiles. (Provided by STM)
- KiCad 8
- Falstad Circuit Simulator
- Audacity: Audio recording and analysis of the output signal. (Freq Spectrum, Noise Calculations)
- Oscilloscope
- Signal Generator
- Guitar Amp & Guitar

## Conclusion

10 Luiz Mendonça, Scientific Project, SS2026

- Goal proposed was achieved. Echo effect is audible on real guitar input.
- Learned a lot about circuit design and how DMA and double buffering actually work in practice.
- Next steps: custom PCB with ground plane, Sallen-Key filters instead of single RC, true-bypass switch, mount STM32 directly on PCB to shrink size, add more effects like chorus/reverb/distortion with footswitch/BLE APP select.
- Audible noise at the output. Measured at 20.83 dB SNR, causes identified and justified (see report for more details).
- Functional Usable Prototype. Pedal works but is not a finished product. There is alot to build upon and refine

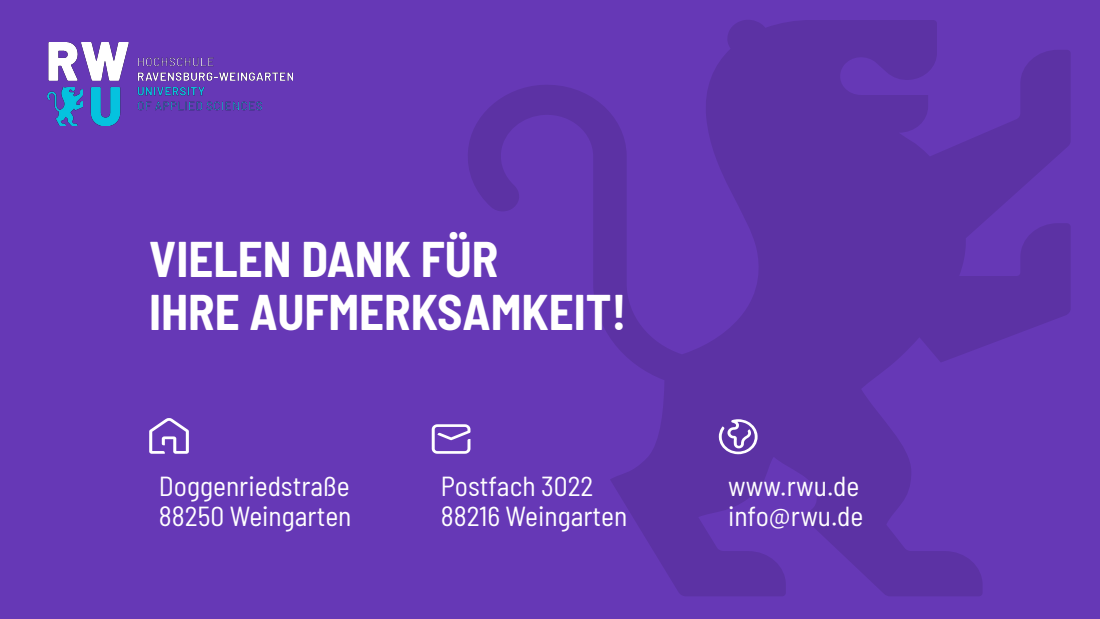
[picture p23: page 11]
Postfach 3022 88216 Weingarten; Doggenriedstraße 88250 Weingarten

VIELEN DANK FÜR
IHRE AUFMERKSAMKEIT!

www.rwu.de
info@rwu.de

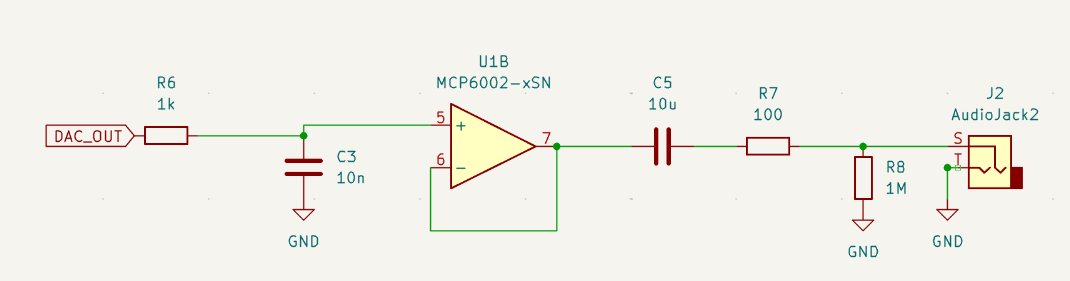
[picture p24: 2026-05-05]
images/analog_backend_schematics.png

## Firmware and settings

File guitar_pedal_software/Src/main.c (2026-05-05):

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
/* Includes ------------------------------------------------------------------*/
#include "main.h"
#include "adc.h"
#include "dac.h"
#include "dma.h"
#include "tim.h"
#include "gpio.h"

/* USER CODE BEGIN Includes */
#include "dsp.h"

/* USER CODE END Includes */

/* USER CODE BEGIN PD */
#define N 256
#define halfN 128

/* USER CODE END PD */


/* USER CODE BEGIN PV */
// DMA1 cannot access DTCM RAM on STM32H7; place buffers in D2 SRAM.
__attribute__((section(".dma_buffer"))) uint16_t adcBuffer[N];
__attribute__((section(".dma_buffer"))) uint16_t dacBuffer[N];

volatile uint32_t dbg_halfCpltCount = 0;
volatile uint32_t dbg_cpltCount = 0;
volatile uint16_t dbg_adcSnapshot[4];
volatile uint16_t dbg_adcMin = 0xFFFF;
volatile uint16_t dbg_adcMax = 0;
volatile uint16_t dbg_dacSnapshot[4];

volatile uint32_t dbg_init_progress = 0;
volatile uint32_t dbg_reset_cause = 0;
volatile uint32_t dbg_fault_type = 0;
volatile uint32_t dbg_fault_CFSR = 0;
volatile uint32_t dbg_fault_HFSR = 0;
volatile uint32_t dbg_fault_MMFAR = 0;
volatile uint32_t dbg_fault_BFAR = 0;
volatile uint32_t dbg_error_handler_hit = 0;

/* USER CODE END PV */

void SystemClock_Config(void);
/* USER CODE BEGIN PFP */
void dsp_algorithm(uint16_t *input, uint16_t *output, int startindex,
                   int endindex);

/* USER CODE END PFP */

/**
  * @brief  The application entry point.
  * @retval int
  */
int main(void)
{

  /* USER CODE BEGIN 1 */
  // Force-reset peripherals: a debug-reset leaves them mid-operation.
  __HAL_RCC_DMA1_CLK_ENABLE();
  __HAL_RCC_DMA1_FORCE_RESET();
  __HAL_RCC_DMA1_RELEASE_RESET();

  NVIC_DisableIRQ(DMA1_Stream0_IRQn);
  NVIC_DisableIRQ(DMA1_Stream1_IRQn);
  NVIC_DisableIRQ(DMAMUX1_OVR_IRQn);
  NVIC_ClearPendingIRQ(DMA1_Stream0_IRQn);
  NVIC_ClearPendingIRQ(DMA1_Stream1_IRQn);
  NVIC_ClearPendingIRQ(DMAMUX1_OVR_IRQn);

  __HAL_RCC_ADC12_CLK_ENABLE();
  __HAL_RCC_ADC12_FORCE_RESET();
  __HAL_RCC_ADC12_RELEASE_RESET();

  __HAL_RCC_DAC12_CLK_ENABLE();
  __HAL_RCC_DAC12_FORCE_RESET();
  __HAL_RCC_DAC12_RELEASE_RESET();

  __HAL_RCC_TIM6_CLK_ENABLE();
  __HAL_RCC_TIM6_FORCE_RESET();
  __HAL_RCC_TIM6_RELEASE_RESET();

  dbg_reset_cause = RCC->RSR;
  __HAL_RCC_CLEAR_RESET_FLAGS();
  /* USER CODE END 1 */

  /* MCU Configuration--------------------------------------------------------*/

  /* Reset of all peripherals, Initializes the Flash interface and the Systick. */
  HAL_Init();

  /* USER CODE BEGIN Init */
  dbg_init_progress = 1;
  /* USER CODE END Init */

  /* Configure the system clock */
  SystemClock_Config();

  /* USER CODE BEGIN SysInit */
  dbg_init_progress = 2;
  /* USER CODE END SysInit */

  /* Initialize all configured peripherals */
  MX_GPIO_Init();
  dbg_init_progress = 3;
  MX_DMA_Init();
  dbg_init_progress = 4;
  MX_ADC1_Init();
  dbg_init_progress = 5;
  MX_DAC1_Init();
  dbg_init_progress = 6;
  MX_TIM6_Init();
  dbg_init_progress = 7;
  /* USER CODE BEGIN 2 */
  HAL_ADC_Start_DMA(&hadc1, (uint32_t *)adcBuffer, N);
  HAL_DAC_Start_DMA(&hdac1, DAC_CHANNEL_1, (uint32_t *)dacBuffer, N,
                    DAC_ALIGN_12B_R);
  HAL_TIM_Base_Start(&htim6);
  dbg_init_progress = 8;
  /* USER CODE END 2 */

  /* Infinite loop */
  /* USER CODE BEGIN WHILE */
  while (1) {
    dbg_init_progress = 9;
    /* USER CODE END WHILE */

    /* USER CODE BEGIN 3 */
  }
  /* USER CODE END 3 */
}

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
/* USER CODE BEGIN 4 */
void HAL_ADC_ConvCpltCallback(ADC_HandleTypeDef *hadc) {
  dsp_algorithm(adcBuffer, dacBuffer, halfN, N);
}

void HAL_ADC_ConvHalfCpltCallback(ADC_HandleTypeDef *hadc) {
  dbg_halfCpltCount++;
  dsp_algorithm(adcBuffer, dacBuffer, 0, halfN);
}
/* USER CODE END 4 */
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


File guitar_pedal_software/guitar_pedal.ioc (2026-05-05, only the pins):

Mcu.UserName=STM32H743VITx
PA3.Signal=ADCx_INP15
PA4.Signal=COMP_DAC11_group

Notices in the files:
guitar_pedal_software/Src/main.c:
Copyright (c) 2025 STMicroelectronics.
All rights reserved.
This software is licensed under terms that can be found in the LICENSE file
